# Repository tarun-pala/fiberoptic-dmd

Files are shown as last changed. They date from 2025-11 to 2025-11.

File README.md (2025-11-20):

# Fiberoptic Dot Matrix Display

The final DMD

Converts a standard 8x8 LED matrix into a smaller dot-matrix-display (DMD) using fiberoptics. Using the [Customization](#customization) section, you can also combine multiple 8x8 LED matrices into a single DMD panel.

## Download

Want to use the default models? [Get them at Printables!](https://www.printables.com/model/375859-fiberoptic-dot-matrix-display)

## Required Parts and Tools

* FDM or SLA 3D printer
* 8x8 LED matrix
* 1mm (0.04") fiberoptic filament
* 1mm (0.04") thick clear plastic sheet
* Superglue
* Pin vise drill with 1mm-1.5mm bit

## Assembly

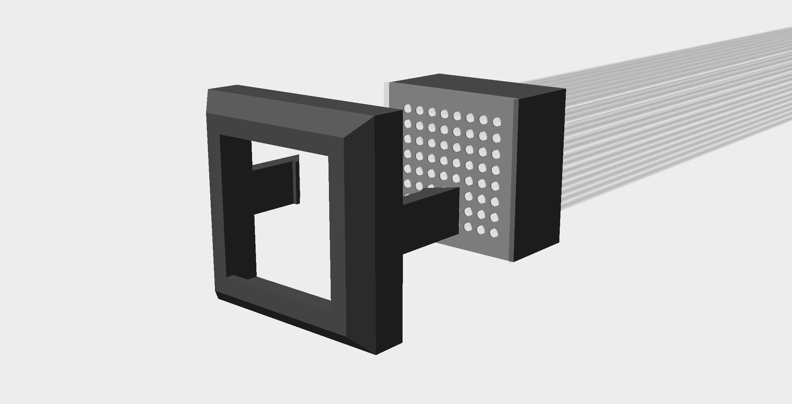
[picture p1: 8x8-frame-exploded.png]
Exploded view


1. Print the bezel, frame, and LED matrix mount.
   * :memo: Check out the [Customization](#customization) section if you want to change the size of the display.
1. Ensure your filament will fit snuggly in each hole of the frame and LED matrix mount.
   * The LED matrix mount is designed to not allow fibers to touch the LED panel but the fibers should insert most of the way.
   * Drill out any undersized holes.
1. Cut the clear plastic sheet to fit within the bezel.
1. Insert the clear plastic sheet into the bezel and snap the frame in behind it.
1. Cut a section of fiberoptic filament for each hole in the frame.
   * :memo: You may find it difficult to assembly later if the lengths of fiber are less than 300mm (~1ft) long.
1. For each fiber, glue one end into the frame and the other end into the corresponding hole on the LED matrix mount.
   * Ensure each fiber is pressed all the way into the frame and LED matrix mount. Recessed fibers will create darker dots in the final display.
   * You may find it easier to glue one row of fibers at a time.
1. Install the LED matrix into the LED matrix mount.

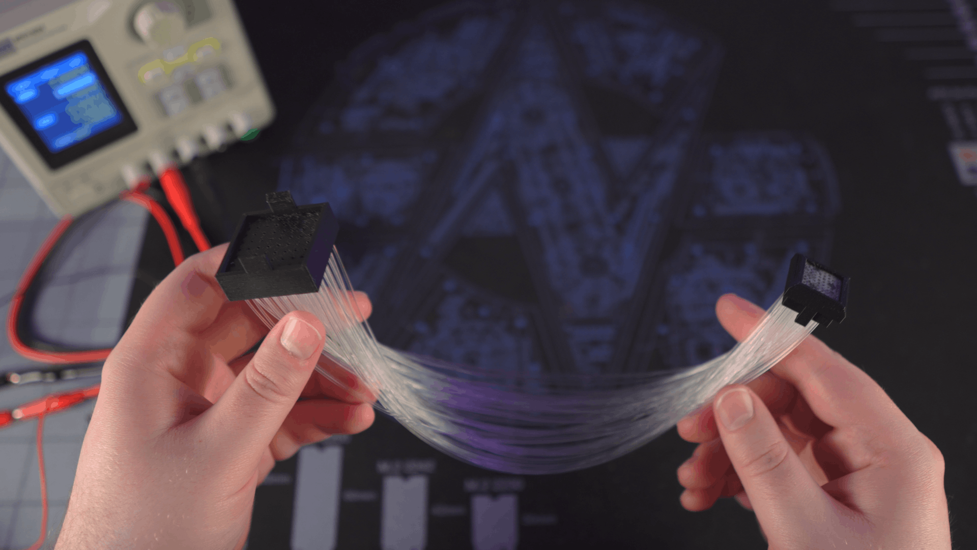
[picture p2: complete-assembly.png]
The complete DMD assembly


## Customization

Want to make a larger display or use different filament diameters? Try customizing these models in OpenSCAD:

1. First, download [OpenSCAD](https://openscad.org/downloads.html) 2021.01 or newer. This is the 3D design software used to create these models.
1. Next, you'll need to download a copy of this project. If you aren't familiar with git/GitHub, I recommend downloading the project as a zip:
   1. Click the green **Code** button on the main page of this repository.
   1. Select **Download ZIP**.
   1. Unzip the contents somewhere on your computer.
1. Launch OpenSCAD and open the included **fiberoptic_dmd.scad** file.
1. Once open, select **Window** from the menu bar and choose **Customizer**. You should see several configuration options appear on the right side.
1. In the customizer panel, expand the **Preview Options** section, locate the **part** drop-down, and choose the part you wish to customize.
1. In the customizer panel, expand the **Model Options** section and customize the model's settings as you see fit.
   * The rendered model may not reflect the changes until you press enter (even if you used the up-down arrows).
1. When you're ready to print your model, first locate the **quality** drop-down in the **Preview Options** section and change it to **Medium** or **High**.
   * Depending on your computer's specs, OpenSCAD may freeze for several seconds while it processes the changes.
1. Once OpenSCAD is responsive again, you'll need to render the model by pressing **F6** or by selecting Design from the main menu and choosing **Render**. Depending on your computer's specs, OpenSCAD may freeze for several minutes while it processes the changes.
1. Once the render is complete, you can directly export an STL of the part by either pressing **F7** or selecting **File**, hovering over **Export**, and choosing **Export as STL...**.

:exclamation: While you can make a 16x8 or larger display from multiple 8x8 matrices, I recommend against it. The display becomes exponentially harder to assemble with each additional row/column. Additional fibers also make the connection between the mount and display far less flexible.

## Related works

I'm not the first to design a fiberoptic DMD. Check out these other cool designs by [elliotmade](https://youtu.be/e9nGw1BpO-Y) and [Dr. Tõnis Gadgets](https://youtu.be/YSTuFIqyf5o)!

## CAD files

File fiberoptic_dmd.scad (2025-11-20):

/**
 BSD 3-Clause License
 
 Copyright (c) 2023, Null Builds
 
 Redistribution and use in source and binary forms, with or without
 modification, are permitted provided that the following conditions are met:
 
 1. Redistributions of source code must retain the above copyright notice, this
    list of conditions and the following disclaimer.
 
 2. Redistributions in binary form must reproduce the above copyright notice,
    this list of conditions and the following disclaimer in the documentation
    and/or other materials provided with the distribution.
 
 3. Neither the name of the copyright holder nor the names of its
    contributors may be used to endorse or promote products derived from
    this software without specific prior written permission.
 
 THIS SOFTWARE IS PROVIDED BY THE COPYRIGHT HOLDERS AND CONTRIBUTORS "AS IS"
 AND ANY EXPRESS OR IMPLIED WARRANTIES, INCLUDING, BUT NOT LIMITED TO, THE
 IMPLIED WARRANTIES OF MERCHANTABILITY AND FITNESS FOR A PARTICULAR PURPOSE ARE
 DISCLAIMED. IN NO EVENT SHALL THE COPYRIGHT HOLDER OR CONTRIBUTORS BE LIABLE
 FOR ANY DIRECT, INDIRECT, INCIDENTAL, SPECIAL, EXEMPLARY, OR CONSEQUENTIAL
 DAMAGES (INCLUDING, BUT NOT LIMITED TO, PROCUREMENT OF SUBSTITUTE GOODS OR
 SERVICES; LOSS OF USE, DATA, OR PROFITS; OR BUSINESS INTERRUPTION) HOWEVER
 CAUSED AND ON ANY THEORY OF LIABILITY, WHETHER IN CONTRACT, STRICT LIABILITY,
 OR TORT (INCLUDING NEGLIGENCE OR OTHERWISE) ARISING IN ANY WAY OUT OF THE USE
 OF THIS SOFTWARE, EVEN IF ADVISED OF THE POSSIBILITY OF SUCH DAMAGE.
 */

/* [Preview Options] */

// Which part to render
part = "matrix_mount"; // [matrix_mount:LED Matrix Mount,frame:Frame,bezel:Bezel]

// Adjusts the quality of curved surfaces at the cost of rendering performance
quality = "low"; // [low:Low,medium:Medium,high:High]

/* [Model Options] */

// How many rows the display has
display_rows = 8;

// How many columns the display has
display_columns = 8;

// The pitch (spacing) of the display dots in mm
display_pitch = 1.9;

// The diameter of the holes the filaments will be pressed into in mm
filament_hole_diameter = 1.25;

// The thickness walls of the filament frame in mm
frame_wall_thickness = 2;

// The thickness of the clear plastic serving as the display surface in mm
display_surface_thickness = 1;

// Adjust the quality of curved surfaces based on the "quality" variable.
$fa = quality == "low" ? 6 : quality == "medium" ? 1 : 0.1;
$fs = quality == "low" ? 2 : quality == "medium" ? 1 : 0.1;

build_part();

/**
 * A small value used during union and difference operations to create a slight overlap between
 * bodies for the purpose of preventing imperceptibly thin walls caused by rounding errors.
 * 
 * @return the value
 */
function epsilon() = 0.01;

/**
 * Switches which part is shown based on the value of the "part" variable.
 * 
 * <p>This function allows multiple parts to be rendered from a single file. It also meets
 * Thingiverse's customizer requirements should I wish to upload there.
 */
module build_part() {
  frame_width = display_columns * display_pitch + frame_wall_thickness * 2;
  frame_height = display_rows * display_pitch + frame_wall_thickness * 2;
  frame_depth = 10;
  
  if (part == "matrix_mount") {
    assert(filament_hole_diameter < 4, "filament_hole_diameter must be less than 4mm.");
    
    rows = 8;
    columns = 8;
    pitch = 4;
    wall_thickness = 2;
    width = columns * pitch + wall_thickness * 2;
    height = rows * pitch + wall_thickness * 2;
    
    translate([-width / 2, -height / 2, 0]) {
      led_matrix_mount(
          filament_hole_diameter = filament_hole_diameter,
          rows = rows,
          columns = columns,
          pitch = pitch,
          wall_thickness = wall_thickness,
          wall_height = 2,
          clip_width = 10,
          clip_height = 4.8,
          clip_reach = 0.5,
          filament_depth = 10,
          light_gate_thickness = 1,
          light_gate_diameter = 0.9
      );
    }
  } else if (part == "frame") {
    translate([-frame_width / 2, -frame_height / 2, 0]) {
      frame(
          filament_hole_diameter = filament_hole_diameter,
          pitch = display_pitch,
          rows = display_rows,
          columns = display_columns,
          wall_thickness = frame_wall_thickness,
          height = frame_depth
      );
    }
  } else if (part == "bezel") {
    allowance = 0.3;
    
    size_bezel_thickness = 2;
    width = frame_width + allowance + size_bezel_thickness * 2;
    height = frame_height + allowance + size_bezel_thickness * 2;
    
    translate([-width / 2, -height / 2, 0]) {
      bezel(
          inner_width = frame_width + allowance,
          inner_height = frame_height + allowance,
          inner_depth = frame_depth / 2,
          display_width = display_columns * display_pitch + allowance,
          display_height = display_rows * display_pitch + allowance,
          front_bezel_thickness = 1,
          size_bezel_thickness = size_bezel_thickness,
          clip_width = 5,
          clip_height = frame_depth / 2 + display_surface_thickness,
          clip_reach = 0.5
      );
    }
  }
}

/**
 * Creates the frame to hold the fiberoptic filaments.
 * 
 * @param filament_hole_diameter the diameter of the hole for the filament in mm
 * @param pitch the pitch of the dots in mm
 * @param rows the number of rows of dots
 * @param columns the number of columns of dots
 * @param wall_thickness the thickness of the outside walls in mm
 * @param height the height of the frame in mm
 */
module frame(filament_hole_diameter, pitch, rows, columns, wall_thickness, height) {
  assert(pitch > filament_hole_diameter, "filament_hole_diameter must be less than pitch.");
  
  size = [
    pitch * columns + wall_thickness * 2,
    pitch * rows + wall_thickness * 2
  ];
  
  linear_extrude(height = height, slices = 1) {
    difference() {
      square(size = size);
      translate([wall_thickness, wall_thickness]) {
        dot_grid(
            dot_diameter = filament_hole_diameter,
            pitch = pitch,
            rows = rows,
            columns = columns
        );
      }
    }
  }
}

/**
 * The mount for attaching the LED matrix to the filaments.
 * 
 * @param filament_hole_diameter the diameter of the holes for each filament in mm
 * @param rows the number of rows of dots
 * @param columns the number of columns of dots
 * @param pitch the pitch of the dots in mm
 * @param wall_thickness the thickness of the walls around the LED matrix in mm
 * @param wall_height the height of the walls around the LED matrix in mm
 * @param clip_width the width of the clips in mm
 * @param clip_height the height of the clips in mm
 * @param clip_reach the distance the clips reach over the other part in mm
 * @param filament_depth the depth the filaments can be inserted into the part in mm
 * @param light_gate_thickness the thickness of panel between the filaments and LEDs in mm
 * @param light_gate_diameter the diameter of the holes allowing light into the filaments in mm
 */
module led_matrix_mount(
    filament_hole_diameter,
    rows,
    columns,
    pitch,
    wall_thickness,
    wall_height,
    clip_width,
    clip_height,
    clip_reach,
    filament_depth,
    light_gate_thickness,
    light_gate_diameter) {
  outer_width = columns * pitch + wall_thickness * 2;
  outer_height = rows * pitch + wall_thickness * 2;
  inner_width = outer_width - wall_thickness * 2;
  inner_height = outer_height - wall_thickness * 2;
  
  union() {
    // Filament holding plate
    linear_extrude(height = filament_depth, slices = 1) {
      hole_plate_profile(
          hole_diameter = filament_hole_diameter,
          rows = rows,
          columns = columns,
          pitch = pitch,
          bezel = wall_thickness
      );
    }
    
    translate([0, 0, filament_depth - epsilon()]) {
      // Light gate
      linear_extrude(height = light_gate_thickness, slices = 1) {
        hole_plate_profile(
            hole_diameter = light_gate_diameter,
            rows = rows,
            columns = columns,
            pitch = pitch,
            bezel = wall_thickness
        );
      }
      
      translate([0, 0, light_gate_thickness - epsilon()]) {
        // Walls
        linear_extrude(height = wall_height, slices = 1) {
          hollow_rectangle(
              outer_size = [outer_width, outer_height],
              inner_size = [inner_width, inner_height]
          );
        }
        
        // Tabs
        for(tab = [0:1]) {
          translate([outer_width * tab, outer_height / 2, wall_height - epsilon()]) {
            rotate([90, 0, tab * 180]) {
              linear_extrude(height = clip_width, slices = 1, center = true) {
                clip_profile(height = clip_height, thickness = wall_thickness, reach = clip_reach);
              }
            }
          }
        }
      }
    }
  }
}
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
